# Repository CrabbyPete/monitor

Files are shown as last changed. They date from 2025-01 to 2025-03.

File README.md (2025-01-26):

# crib

## Getting started

To make it easy for you to get started with GitLab, here's a list of recommended next steps.

Already a pro? Just edit this README.md and make it your own. Want to make it easy? [Use the template at the bottom](#editing-this-readme)!

## Add your files

- [ ] [Create](https://docs.gitlab.com/ee/user/project/repository/web_editor.html#create-a-file) or [upload](https://docs.gitlab.com/ee/user/project/repository/web_editor.html#upload-a-file) files
- [ ] [Add files using the command line](https://docs.gitlab.com/ee/gitlab-basics/add-file.html#add-a-file-using-the-command-line) or push an existing Git repository with the following command:

```
cd existing_repo
git remote add origin https://gitlab.com/CrabbyPete/crib.git
git branch -M main
git push -uf origin main
```

## Integrate with your tools

- [ ] [Set up project integrations](https://gitlab.com/CrabbyPete/crib/-/settings/integrations)

## Collaborate with your team

- [ ] [Invite team members and collaborators](https://docs.gitlab.com/ee/user/project/members/)
- [ ] [Create a new merge request](https://docs.gitlab.com/ee/user/project/merge_requests/creating_merge_requests.html)
- [ ] [Automatically close issues from merge requests](https://docs.gitlab.com/ee/user/project/issues/managing_issues.html#closing-issues-automatically)
- [ ] [Enable merge request approvals](https://docs.gitlab.com/ee/user/project/merge_requests/approvals/)
- [ ] [Set auto-merge](https://docs.gitlab.com/ee/user/project/merge_requests/merge_when_pipeline_succeeds.html)

## Test and Deploy

Use the built-in continuous integration in GitLab.

- [ ] [Get started with GitLab CI/CD](https://docs.gitlab.com/ee/ci/quick_start/index.html)
- [ ] [Analyze your code for known vulnerabilities with Static Application Security Testing (SAST)](https://docs.gitlab.com/ee/user/application_security/sast/)
- [ ] [Deploy to Kubernetes, Amazon EC2, or Amazon ECS using Auto Deploy](https://docs.gitlab.com/ee/topics/autodevops/requirements.html)
- [ ] [Use pull-based deployments for improved Kubernetes management](https://docs.gitlab.com/ee/user/clusters/agent/)
- [ ] [Set up protected environments](https://docs.gitlab.com/ee/ci/environments/protected_environments.html)

***

# Editing this README

When you're ready to make this README your own, just edit this file and use the handy template below (or feel free to structure it however you want - this is just a starting point!). Thanks to [makeareadme.com](https://www.makeareadme.com/) for this template.

## Suggestions for a good README

Every project is different, so consider which of these sections apply to yours. The sections used in the template are suggestions for most open source projects. Also keep in mind that while a README can be too long and detailed, too long is better than too short. If you think your README is too long, consider utilizing another form of documentation rather than cutting out information.

## Name
Choose a self-explaining name for your project.

## Description
Let people know what your project can do specifically. Provide context and add a link to any reference visitors might be unfamiliar with. A list of Features or a Background subsection can also be added here. If there are alternatives to your project, this is a good place to list differentiating factors.

## Badges
On some READMEs, you may see small images that convey metadata, such as whether or not all the tests are passing for the project. You can use Shields to add some to your README. Many services also have instructions for adding a badge.

## Visuals
Depending on what you are making, it can be a good idea to include screenshots or even a video (you'll frequently see GIFs rather than actual videos). Tools like ttygif can help, but check out Asciinema for a more sophisticated method.

## Installation
Within a particular ecosystem, there may be a common way of installing things, such as using Yarn, NuGet, or Homebrew. However, consider the possibility that whoever is reading your README is a novice and would like more guidance. Listing specific steps helps remove ambiguity and gets people to using your project as quickly as possible. If it only runs in a specific context like a particular programming language version or operating system or has dependencies that have to be installed manually, also add a Requirements subsection.

## Usage
Use examples liberally, and show the expected output if you can. It's helpful to have inline the smallest example of usage that you can demonstrate, while providing links to more sophisticated examples if they are too long to reasonably include in the README.

## Support
Tell people where they can go to for help. It can be any combination of an issue tracker, a chat room, an email address, etc.

## Roadmap
If you have ideas for releases in the future, it is a good idea to list them in the README.

## Contributing
State if you are open to contributions and what your requirements are for accepting them.

For people who want to make changes to your project, it's helpful to have some documentation on how to get started. Perhaps there is a script that they should run or some environment variables that they need to set. Make these steps explicit. These instructions could also be useful to your future self.

You can also document commands to lint the code or run tests. These steps help to ensure high code quality and reduce the likelihood that the changes inadvertently break something. Having instructions for running tests is especially helpful if it requires external setup, such as starting a Selenium server for testing in a browser.

## Authors and acknowledgment
Show your appreciation to those who have contributed to the project.

## License
For open source projects, say how it is licensed.

## Project status
If you have run out of energy or time for your project, put a note at the top of the README saying that development has slowed down or stopped completely. Someone may choose to fork your project or volunteer to step in as a maintainer or owner, allowing your project to keep going. You can also make an explicit request for maintainers.

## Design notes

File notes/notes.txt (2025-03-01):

How to build:

1. Install Bullseye 64bit Lite OS
2. sudo apt update, sudo apt upgrade
3. copy config.txt
4. copy /etc/asound.conf

Audio:
    with no asound.conf: # volume is very low lasts 2 seconds
    arecord -f S32_LE -D hw:0,0 -c 2 -r 48000 -d 2 test.wav

    Stream audio to speakers
    gst-launch-1.0 alsasrc device=hw:0 ! autoaudiosink
    gst-launch-1.0 alsasrc device=hw:0 ! volume volume=3.0 ! autoaudiosink

    Audio only to VLC
    gst-launch-1.0 alsasrc device=hw:1,0 ! mulawenc ! rtppcmupay ! udpsink host=224.1.1.1 auto-multicast=true port=5000
    Now VLC works going to rtp://224.1.1.1:5000 and has the correct codec that I wanted.

Install gstream python

    sudo apt install libcairo2-dev pkg-config python3-dev
    pip install pycairo
    pip install PyGObject

To add awswebrtcsink
    https://gitlab.freedesktop.org/gstreamer/gst-plugins-rs/-/blob/main/net/webrtc/README.md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

Links:
https://learn.adafruit.com/adafruit-max98357-i2s-class-d-mono-amp/raspberry-pi-wiring
https://www.raspberrypi.com/documentation/computers/camera_software.html
https://sourceforge.net/p/raspberry-gpio-python/wiki
https://www.linkedin.com/pulse/streaming-camera-video-aws-kinesis-streams-using-python-kashif-ayub-map9f/
https://docs.arducam.com/Raspberry-Pi-Camera/Low-Light/quick-start/#native-camera
https://github.com/dave-malone/aws-kvs-webrtc-demo-for-raspberry-pi

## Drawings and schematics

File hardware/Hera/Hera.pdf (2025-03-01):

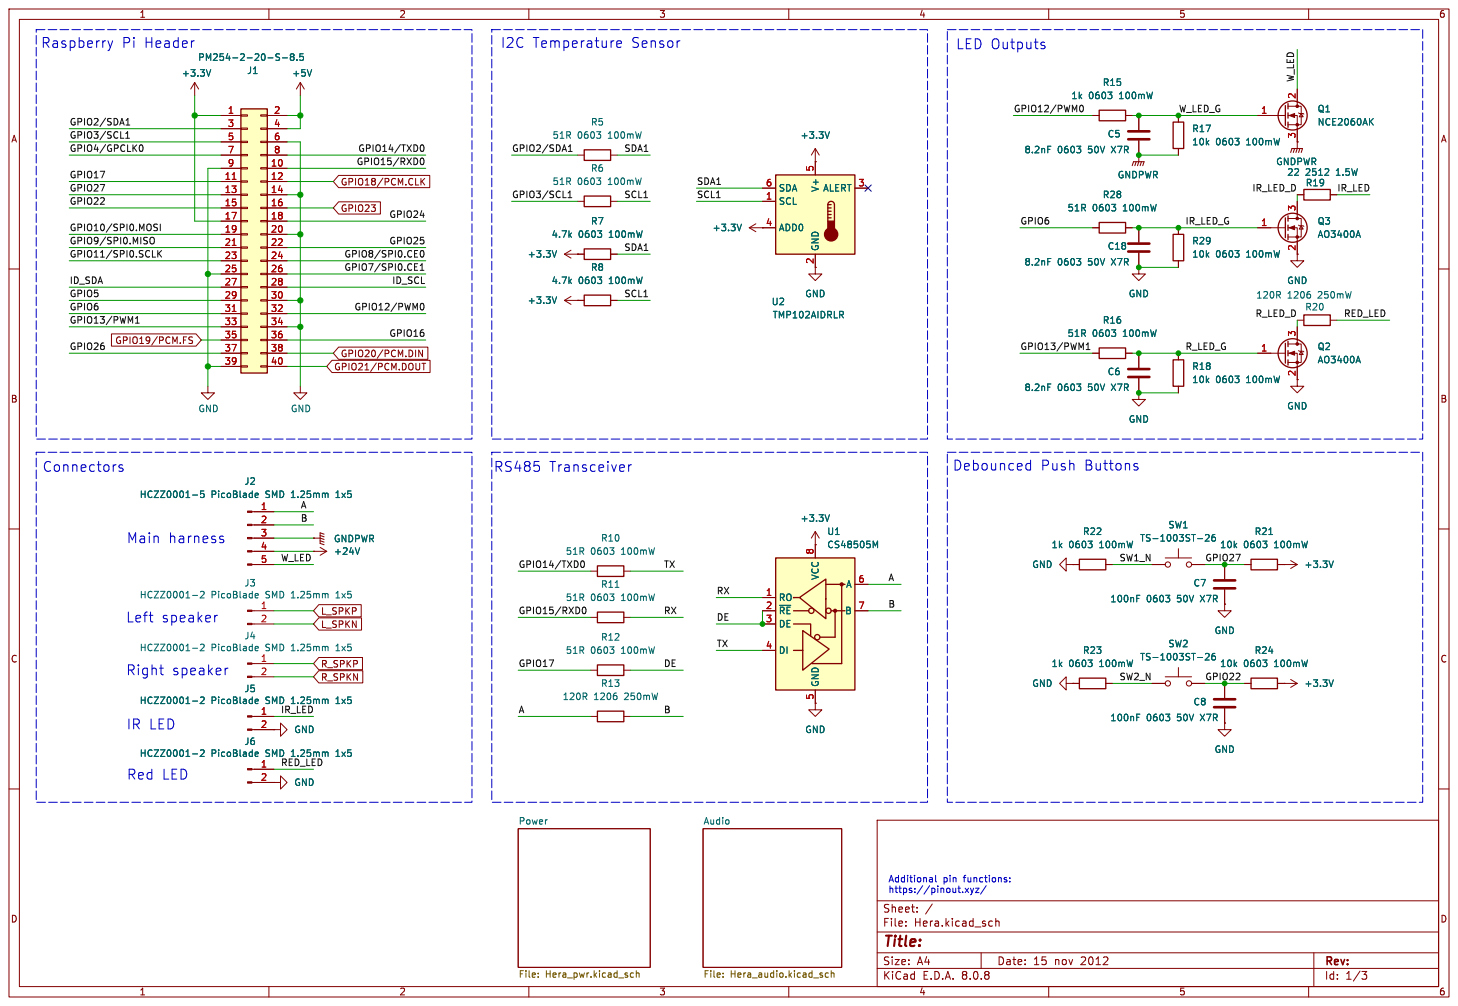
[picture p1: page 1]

GND GND GPIO20/PCM.DIN GPIO21/PCM.DOUT GPIO18/PCM.CLK

Id: 1/3 Title: File: Hera.kicad_sch Sheet: / Audio File: Hera_audio.kicad_sch Power File: Hera_pwr.kicad_sch

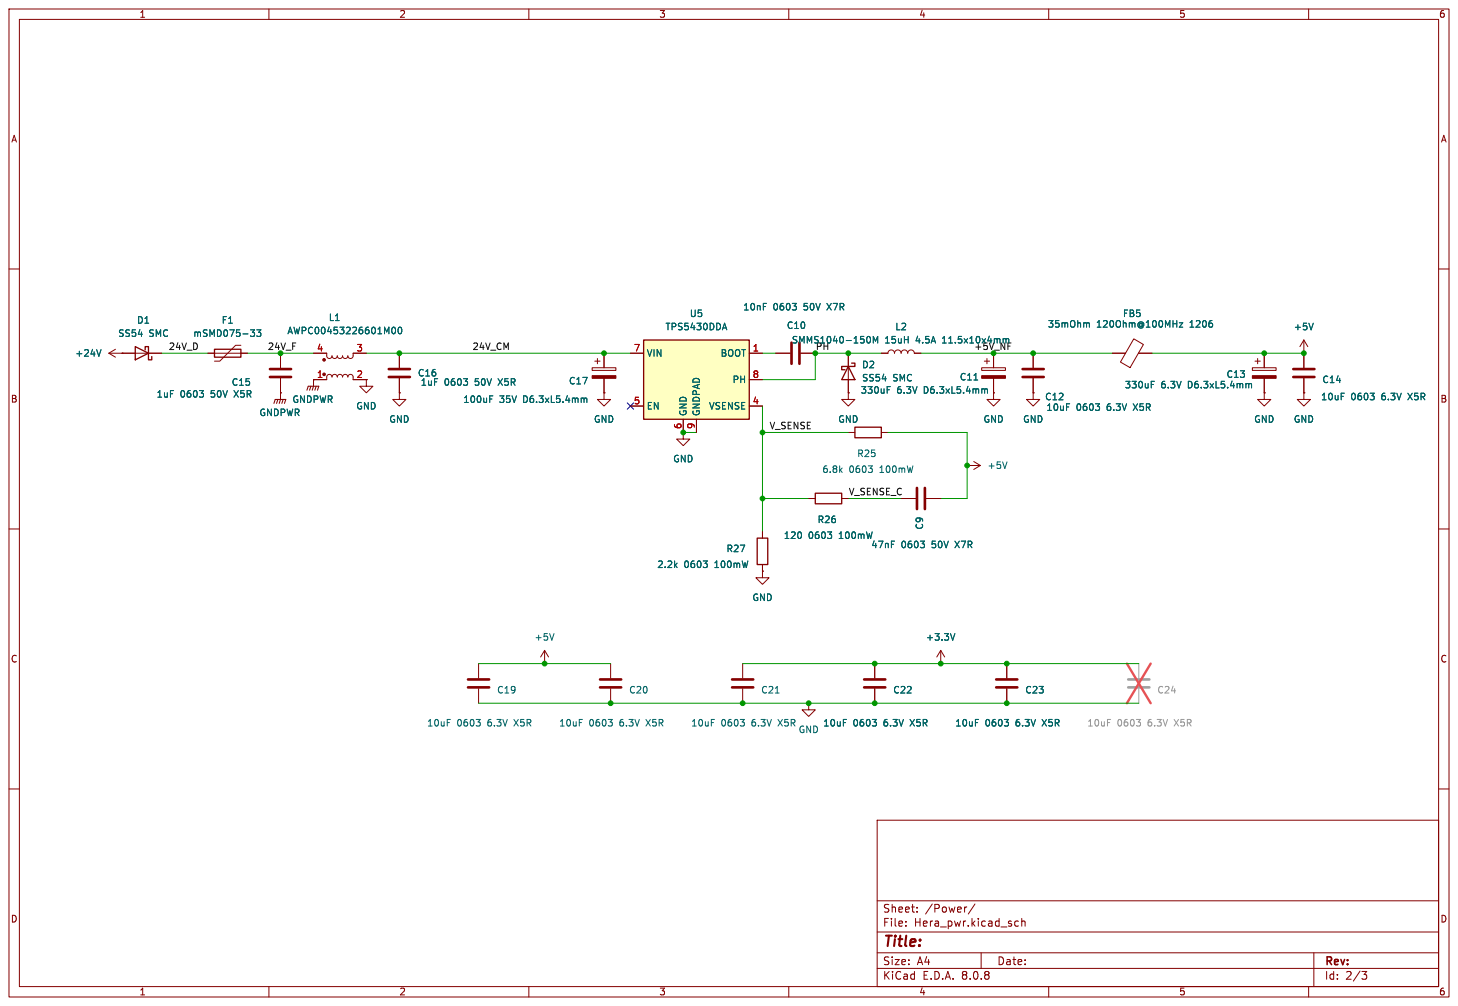
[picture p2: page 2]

Id: 2/3 Title: File: Hera_pwr.kicad_sch Sheet: /Power/ C9

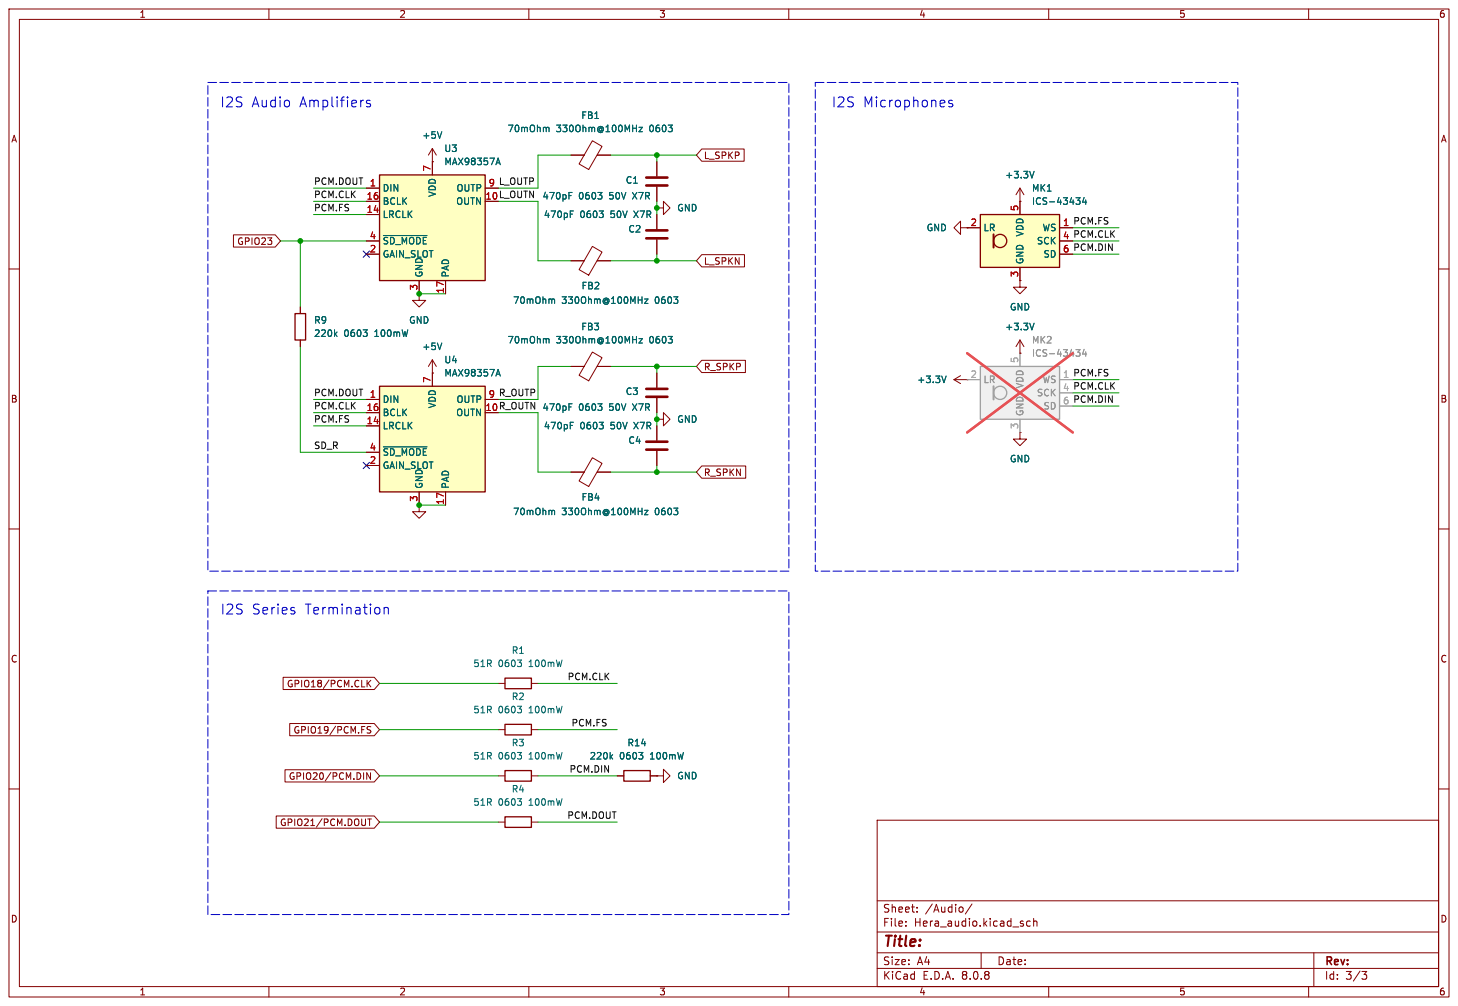
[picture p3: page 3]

PCM.DOUT PCM.FS

R_SPKP GPIO19/PCM.FS GPIO18/PCM.CLK GPIO20/PCM.DIN

Id: 3/3 Title: File: Hera_audio.kicad_sch Sheet: /Audio/ R2

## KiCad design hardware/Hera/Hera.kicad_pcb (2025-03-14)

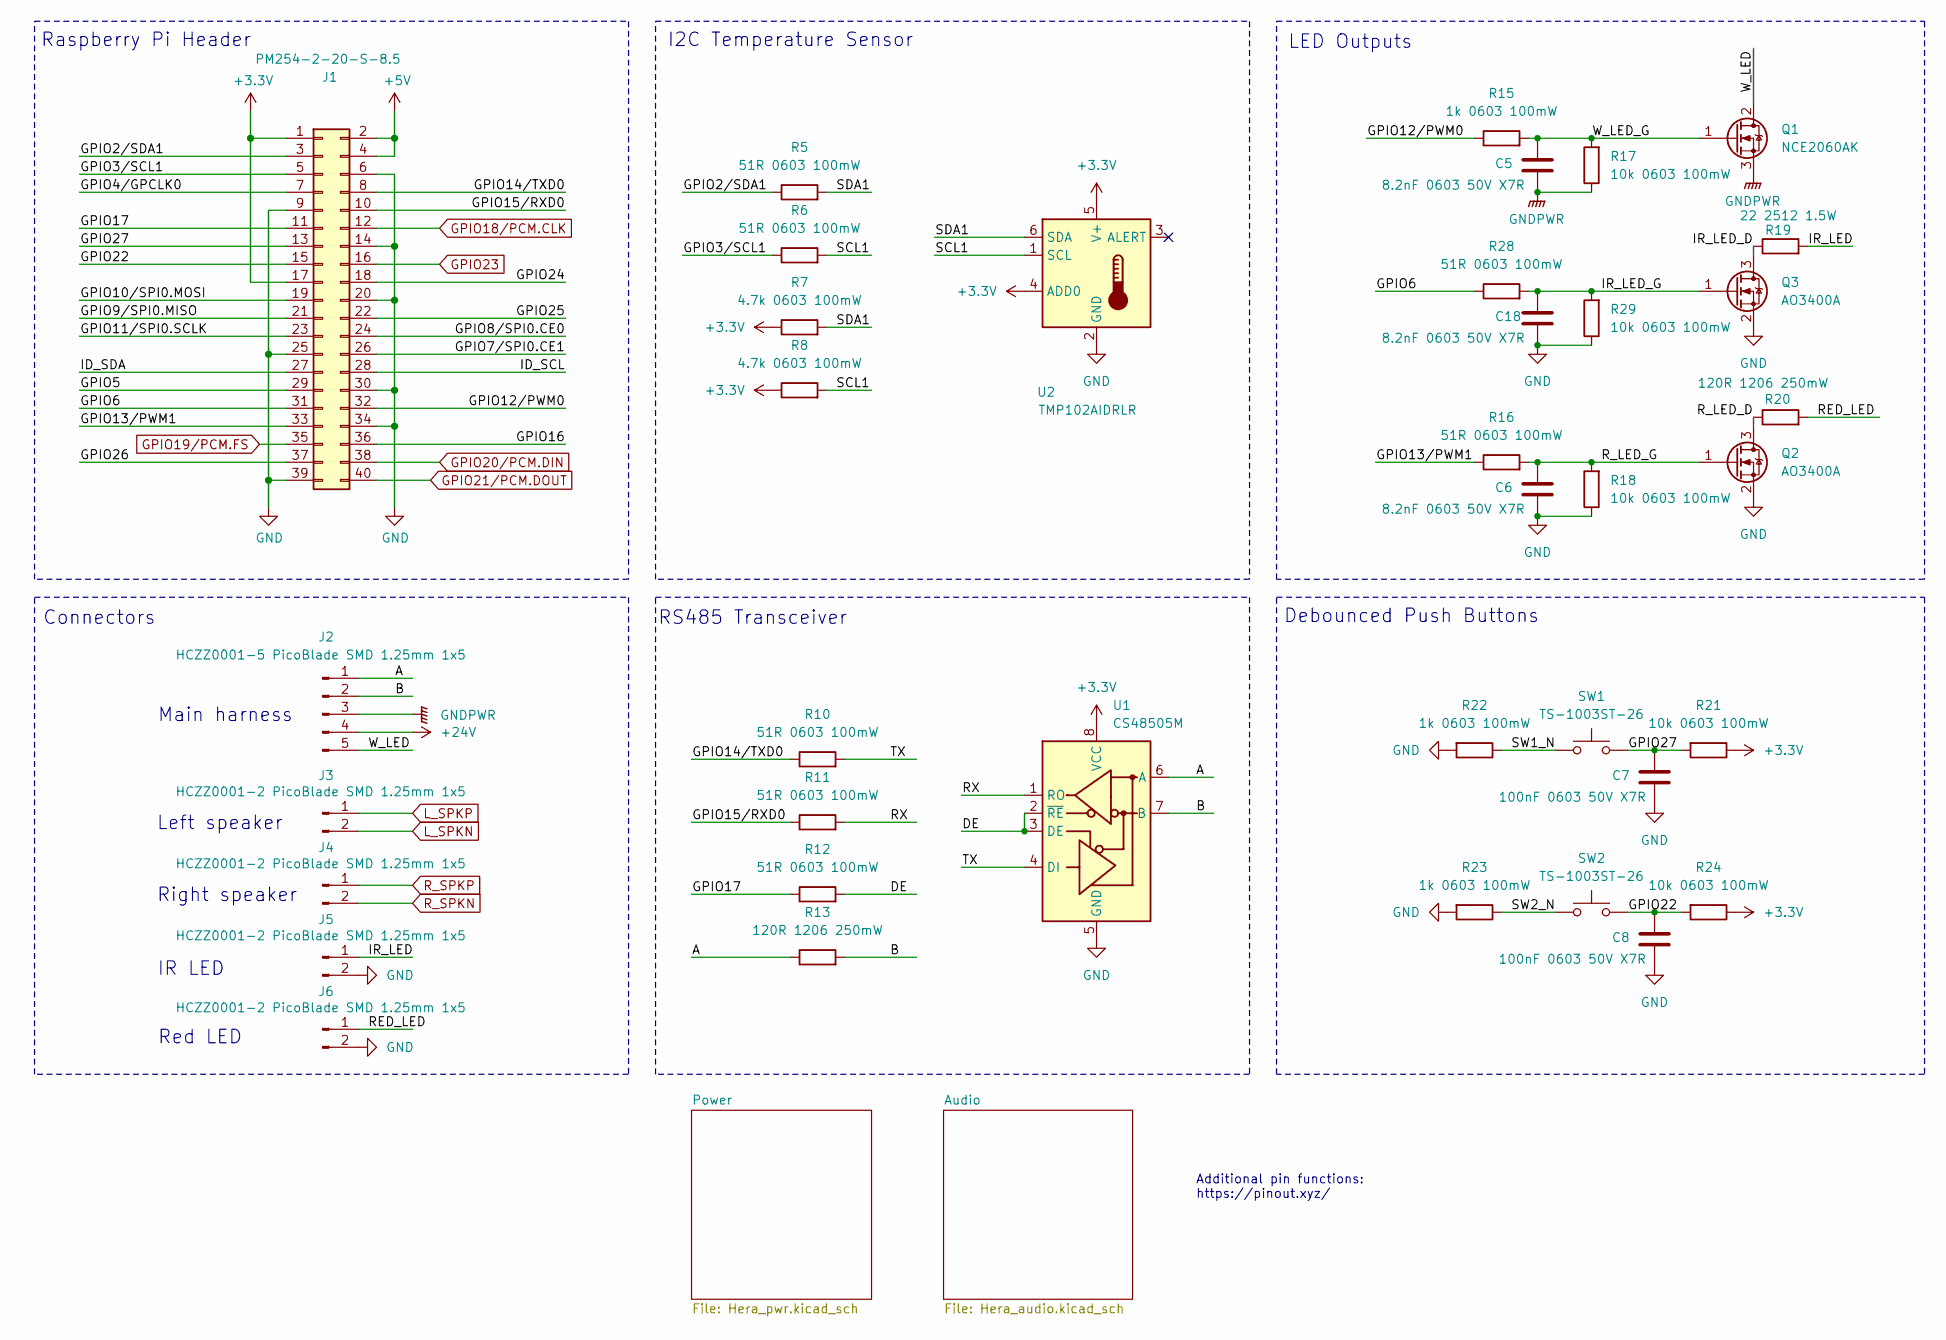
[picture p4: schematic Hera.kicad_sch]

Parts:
C5, C6, C18: 8.2nF 0603 50V X7R; C_0603_1608Metric
C7, C8: 100nF 0603 50V X7R; C_0603_1608Metric
J1: PM254-2-20-S-8.5; PinSocket_2x20_P2.54mm_Vertical_SMD
J2: HCZZ0001-5 PicoBlade SMD 1.25mm 1x5; Molex_PicoBlade_53261-0571_1x05-1MP_P1.25mm_Horizontal
J3, J4, J5, J6: HCZZ0001-2 PicoBlade SMD 1.25mm 1x5; Molex_PicoBlade_53261-0271_1x02-1MP_P1.25mm_Horizontal
Q1: NCE2060AK; TO-252-2
Q2, Q3: AO3400A; SOT-23
R5, R6, R10, R11, R12, R16, R28: 51R 0603 100mW; R_0603_1608Metric
R7, R8: 4.7k 0603 100mW; R_0603_1608Metric
R13, R20: 120R 1206 250mW; R_1206_3216Metric
R15, R22, R23: 1k 0603 100mW; R_0603_1608Metric
R17, R18, R21, R24, R29: 10k 0603 100mW; R_0603_1608Metric
R19: 22 2512 1.5W; R_2512_6332Metric
SW1, SW2: TS-1003ST-26; SW_Push_1P1T_NO_CK_PTS125Sx43PSMTR
U1: CS48505M; MSOP-8_3x3mm_P0.65mm
U2: TMP102AIDRLR; SOT-563

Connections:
+3.3V: J1.1, J1.17, R7.1, R8.1, R21.1, R24.1, U1.8 (VCC), U2.4 (ADD0), U2.5 (V+); also elsewhere on the board
+5V: J1.2, J1.4; also elsewhere on the board
+24V: J2.4; also elsewhere on the board
/A: J2.1, R13.1, U1.6 (A)
/B: J2.2, R13.2, U1.7 (B)
/DE: R12.2, U1.2 (~RE), U1.3 (DE)
/GPIO2/SDA1: J1.3, R5.1
/GPIO3/SCL1: J1.5, R6.1
/GPIO4/GPCLK0: J1.7
/GPIO5: J1.29
/GPIO6: J1.31, R28.1
/GPIO7/SPI0.CE1: J1.26
/GPIO8/SPI0.CE0: J1.24
/GPIO9/SPI0.MISO: J1.21
/GPIO10/SPI0.MOSI: J1.19
/GPIO11/SPI0.SCLK: J1.23
/GPIO12/PWM0: J1.32, R15.1
/GPIO13/PWM1: J1.33, R16.1
/GPIO14/TXD0: J1.8, R10.1
/GPIO15/RXD0: J1.10, R11.1
/GPIO16: J1.36
/GPIO17: J1.11, R12.1
/GPIO22: C8.1, J1.15, R24.2, SW2.2
/GPIO24: J1.18
/GPIO25: J1.22
/GPIO26: J1.37
/GPIO27: C7.1, J1.13, R21.2, SW1.2
/ID_SCL: J1.28
/ID_SDA: J1.27
/IR_LED: J5.1, R19.2
/IR_LED_D: Q3.3 (D), R19.1
/IR_LED_G: C18.1, Q3.1 (G), R28.2, R29.2
/RED_LED: J6.1, R20.2
/RX: R11.2, U1.1 (RO)
/R_LED_D: Q2.3 (D), R20.1
/R_LED_G: C6.1, Q2.1 (G), R16.2, R18.2
/SCL1: R6.2, R8.2, U2.1 (SCL)
/SDA1: R5.2, R7.2, U2.6 (SDA)
/SW1_N: R22.1, SW1.1
/SW2_N: R23.1, SW2.1
/TX: R10.2, U1.4 (DI)
/W_LED: J2.5, Q1.2 (D)
/W_LED_G: C5.1, Q1.1 (G), R15.2, R17.2
GND: C6.2, C7.2, C8.2, C18.2, J1.6, J1.9, J1.14, J1.20, J1.25, J1.30, J1.34, J1.39, J5.2, J6.2, Q2.2 (S), Q3.2 (S), R18.1, R22.2, R23.2, R29.1, U1.5 (GND), U2.2 (GND); also elsewhere on the board
GNDPWR: C5.2, J2.3, Q1.3 (S), R17.1; also elsewhere on the board
GPIO18/PCM.CLK: J1.12; also elsewhere on the board
GPIO19/PCM.FS: J1.35; also elsewhere on the board
GPIO20/PCM.DIN: J1.38; also elsewhere on the board
GPIO21/PCM.DOUT: J1.40; also elsewhere on the board
GPIO23: J1.16; also elsewhere on the board
L_SPKN: J3.2; also elsewhere on the board
L_SPKP: J3.1; also elsewhere on the board
R_SPKN: J4.2; also elsewhere on the board
R_SPKP: J4.1; also elsewhere on the board

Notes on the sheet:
Red LED
RS485 Transceiver
Main harness
IR LED
Right speaker
Left speaker
LED Outputs
Raspberry Pi Header
Connectors
I2C Temperature Sensor
Debounced Push Buttons
Additional pin functions: https://pinout.xyz/

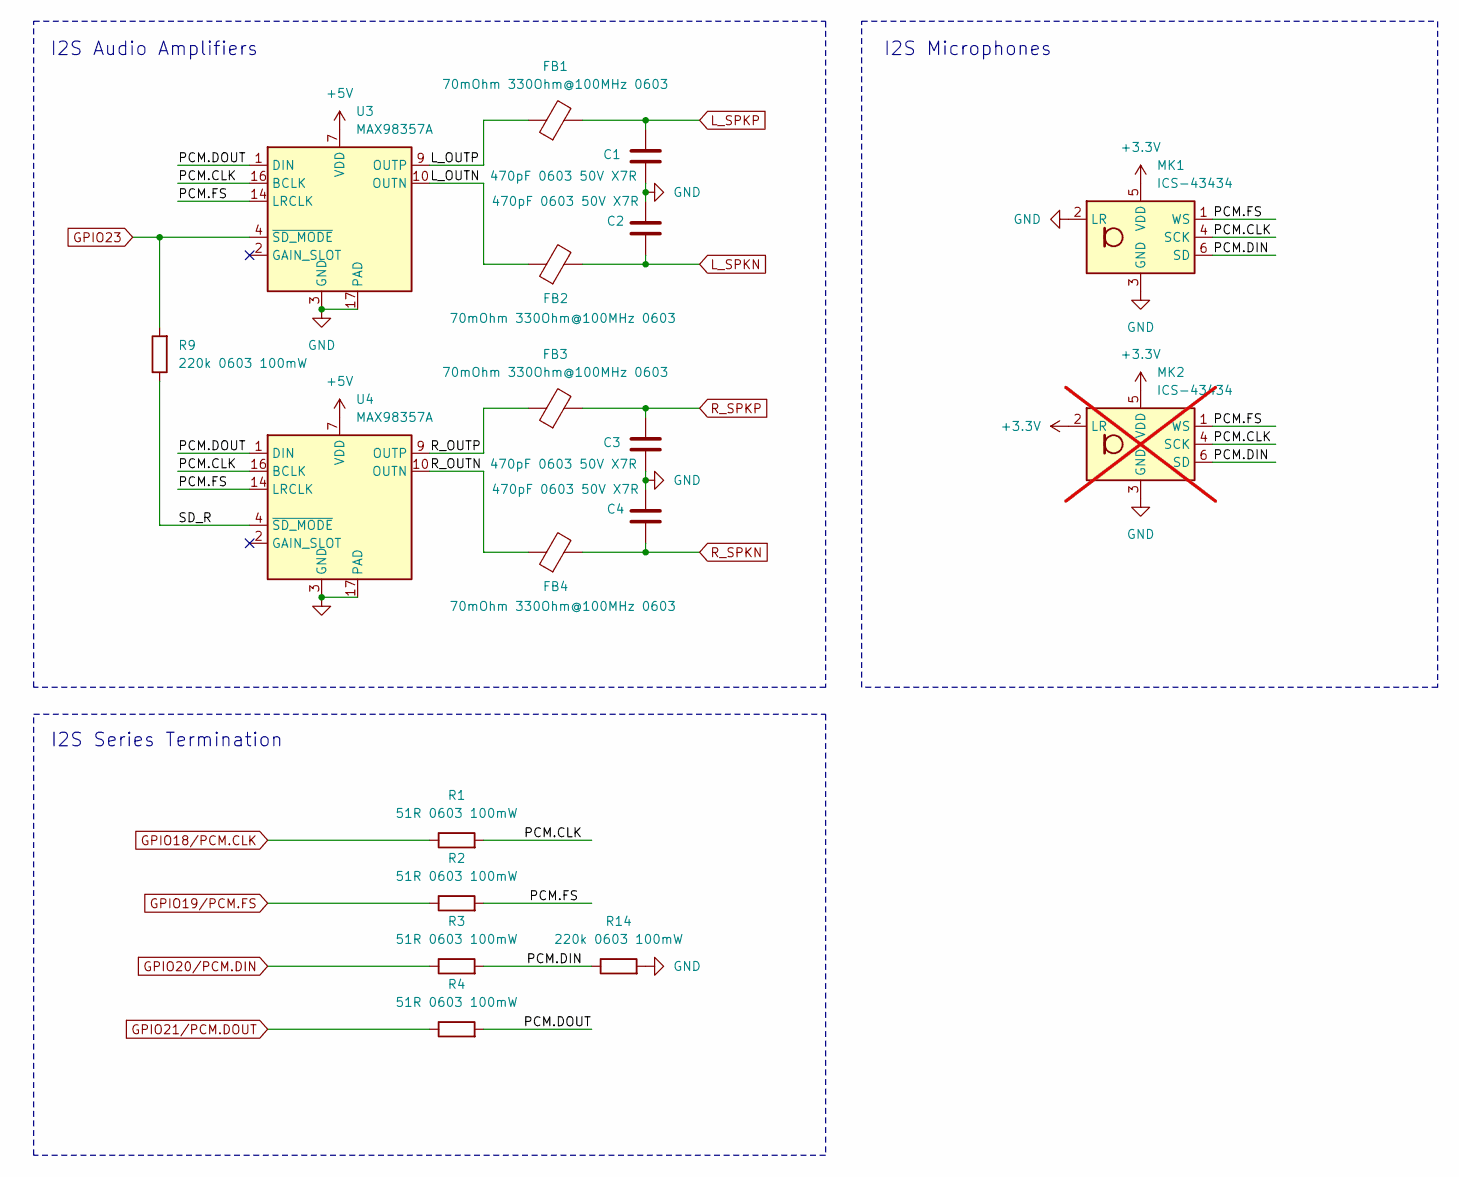
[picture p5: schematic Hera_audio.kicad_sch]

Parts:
C1, C2, C3, C4: 470pF 0603 50V X7R; C_0603_1608Metric
FB1, FB2, FB3, FB4: 70mOhm 330Ohm@100MHz 0603; L_0603_1608Metric
MK1: ICS-43434; InvenSense_ICS-43434-6_3.5x2.65mm
MK2: ICS-43434; InvenSense_ICS-43434-6_3.5x2.65mm; not fitted
R1, R2, R3, R4: 51R 0603 100mW; R_0603_1608Metric
R9, R14: 220k 0603 100mW; R_0603_1608Metric
U3, U4: MAX98357A; TQFN-16-1EP_3x3mm_P0.5mm_EP1.23x1.23mm

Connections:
+3.3V: MK1.5 (VDD), MK2.2 (LR), MK2.5 (VDD); also elsewhere on the board
+5V: U3.7 (VDD), U3.8 (VDD), U4.7 (VDD), U4.8 (VDD); also elsewhere on the board
/Audio/L_OUTN: FB2.1, U3.10 (OUTN)
/Audio/L_OUTP: FB1.1, U3.9 (OUTP)
/Audio/PCM.CLK: MK1.4 (SCK), MK2.4 (SCK), R1.2, U3.16 (BCLK), U4.16 (BCLK)
/Audio/PCM.DIN: MK1.6 (SD), MK2.6 (SD), R3.2, R14.1
/Audio/PCM.DOUT: R4.2, U3.1 (DIN), U4.1 (DIN)
/Audio/PCM.FS: MK1.1 (WS), MK2.1 (WS), R2.2, U3.14 (LRCLK), U4.14 (LRCLK)
/Audio/R_OUTN: FB4.1, U4.10 (OUTN)
/Audio/R_OUTP: FB3.1, U4.9 (OUTP)
/Audio/SD_R: R9.1, U4.4 (~SD_MODE)
GND: C1.2, C2.1, C3.2, C4.1, MK1.2 (LR), MK1.3 (GND), MK2.3 (GND), R14.2, U3.3 (GND), U3.11 (GND), U3.15 (GND), U3.17 (PAD), U4.3 (GND), U4.11 (GND), U4.15 (GND), U4.17 (PAD); also elsewhere on the board
GPIO18/PCM.CLK: R1.1; also elsewhere on the board
GPIO19/PCM.FS: R2.1; also elsewhere on the board
GPIO20/PCM.DIN: R3.1; also elsewhere on the board
GPIO21/PCM.DOUT: R4.1; also elsewhere on the board
GPIO23: R9.2, U3.4 (~SD_MODE); also elsewhere on the board
L_SPKN: C2.2, FB2.2; also elsewhere on the board
L_SPKP: C1.1, FB1.2; also elsewhere on the board
R_SPKN: C4.2, FB4.2; also elsewhere on the board
R_SPKP: C3.1, FB3.2; also elsewhere on the board

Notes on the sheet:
I2S Audio Amplifiers
I2S Microphones
I2S Series Termination

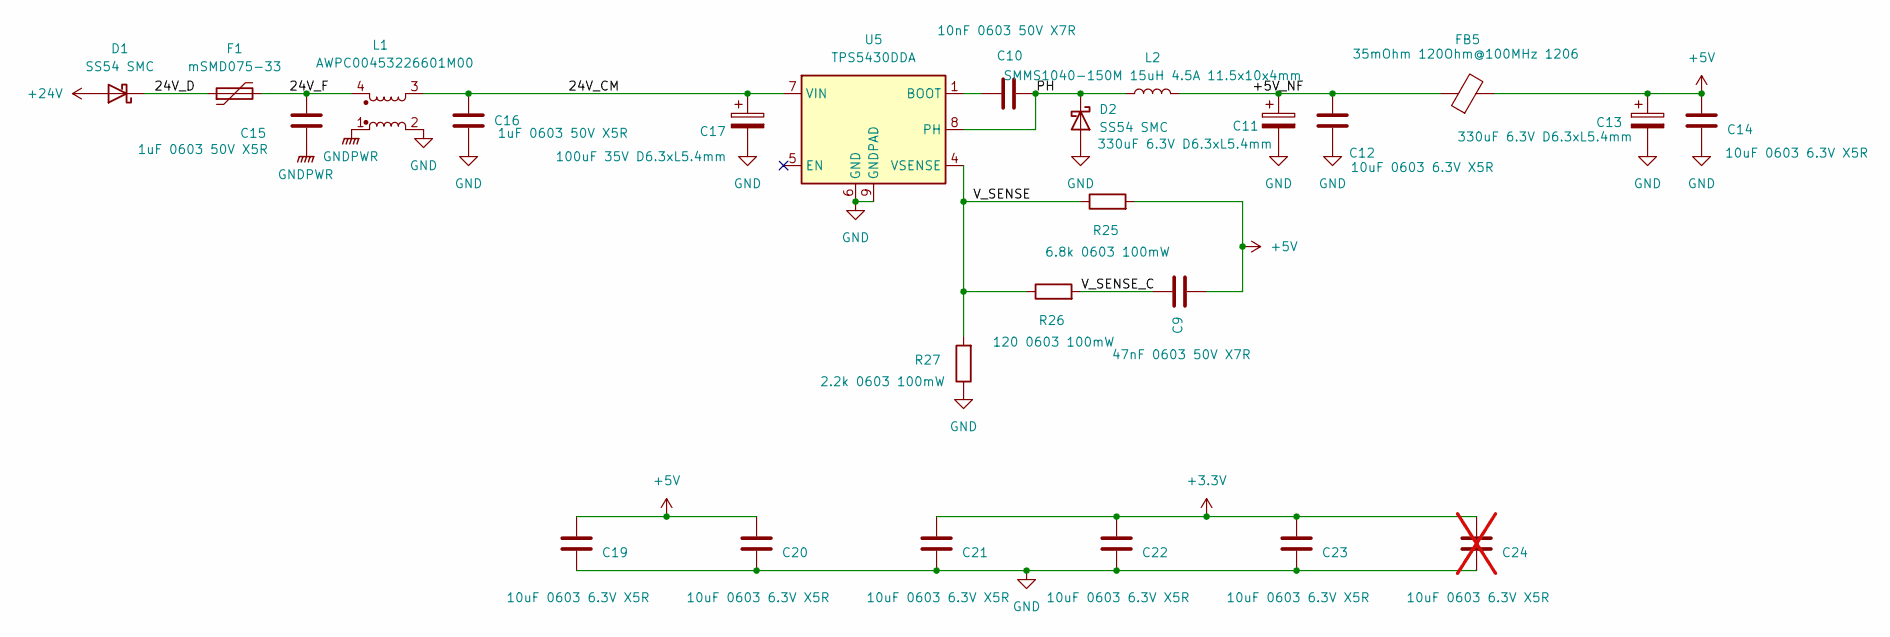
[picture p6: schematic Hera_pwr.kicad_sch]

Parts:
C9: 47nF 0603 50V X7R; C_0603_1608Metric
C10: 10nF 0603 50V X7R; C_0603_1608Metric
C11, C13: 330uF 6.3V D6.3xL5.4mm; CP_Elec_6.3x5.4
C12, C14, C19, C20, C21, C22, C23: 10uF 0603 6.3V X5R; C_0603_1608Metric
C15, C16: 1uF 0603 50V X5R; C_0603_1608Metric
C17: 100uF 35V D6.3xL5.4mm; CP_Elec_6.3x5.4
C24: 10uF 0603 6.3V X5R; C_0603_1608Metric; not fitted
D1, D2: SS54 SMC; D_SMC
F1: mSMD075-33; Fuse_1812_4532Metric
FB5: 35mOhm 120Ohm@100MHz 1206; L_1206_3216Metric
L1: AWPC00453226601M00; L_CommonModeChoke_4.5x3.2
L2: SMMS1040-150M 15uH 4.5A 11.5x10x4mm; L_APV_APH1040
R25: 6.8k 0603 100mW; R_0603_1608Metric
R26: 120 0603 100mW; R_0603_1608Metric
R27: 2.2k 0603 100mW; R_0603_1608Metric
U5: TPS5430DDA; TI_SO-PowerPAD-8_ThermalVias

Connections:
+3.3V: C21.2, C22.2, C23.2, C24.2; also elsewhere on the board
+5V: C9.2, C13.1, C14.2, C19.2, C20.2, FB5.2, R25.2; also elsewhere on the board
+24V: D1.2 (A); also elsewhere on the board
/Power/24V_CM: C16.2, C17.1, L1.3, U5.7 (VIN)
/Power/24V_D: D1.1 (K), F1.1
/Power/24V_F: C15.2, F1.2, L1.4
/Power/+5V_NF: C11.1, C12.2, FB5.1, L2.2
/Power/PH: C10.1, D2.1 (K), L2.1, U5.8 (PH)
/Power/V_SENSE: R25.1, R26.1, R27.2, U5.4 (VSENSE)
/Power/V_SENSE_C: C9.1, R26.2
GND: C11.2, C12.1, C13.2, C14.1, C16.1, C17.2, C19.1, C20.1, C21.1, C22.1, C23.1, C24.1, D2.2 (A), L1.2, R27.1, U5.6 (GND), U5.9 (GNDPAD); also elsewhere on the board
GNDPWR: C15.1, L1.1; also elsewhere on the board
unnamed: C10.2, U5.1 (BOOT)

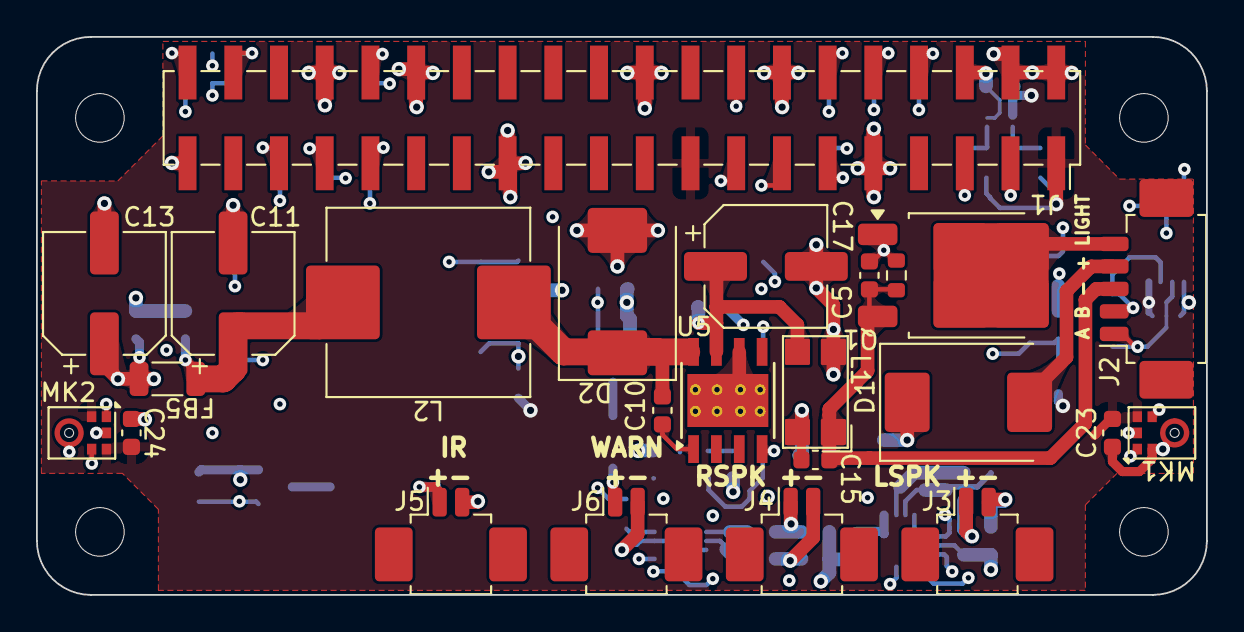
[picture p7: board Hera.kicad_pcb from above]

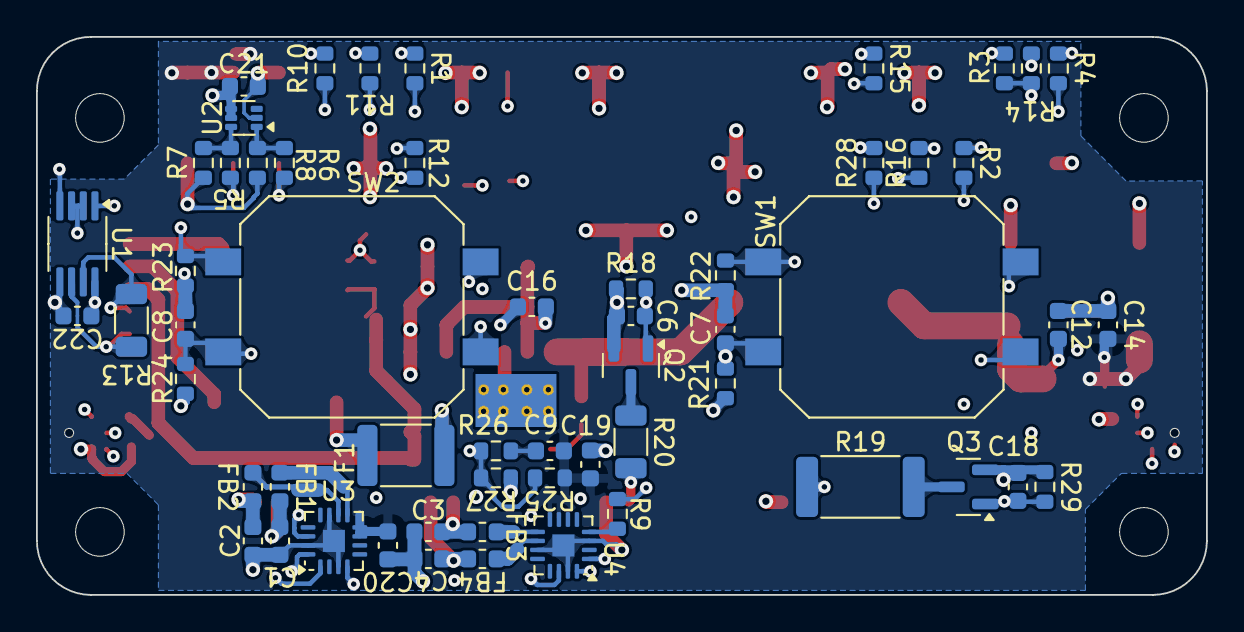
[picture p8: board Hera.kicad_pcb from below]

Board: 6 copper layers, 65.0 x 31.0 mm, 85 parts (57 on the bottom side), 58 nets.

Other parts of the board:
MH1, MH2, MH3, MH4: MountingHole_2.7mm_M2.5

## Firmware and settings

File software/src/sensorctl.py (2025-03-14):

#!/usr/bin/env python3
import os
import time
import smbus2
import psutil
import subprocess
import RPi.GPIO as GPIO

# Local imports
from log        import log
from status     import state
from bare485    import Modbus

MIN_DUTY = 0
MAX_DUTY = 100
MOTOR_CHANNEL = '/dev/ttyS0' # If you uses the USB use this /dev/ttyUSB0'

BUTTON_1_CHANNEL = 27
BUTTON_2_CHANNEL = 22

LED_CHANNEL = 12        # PWM LED channel
LED_FREQUENCY = 10000
IR_LED_CHANNEL = 6
RED_LED_CHANNEL = 13
SPEAKERS = 23

HOME = os.path.dirname(os.path.realpath(__file__))

GPIO.setwarnings(False)
GPIO.setmode(GPIO.BCM)

GPIO.setup(LED_CHANNEL, GPIO.OUT )
GPIO.setup(IR_LED_CHANNEL, GPIO.OUT )
GPIO.setup(RED_LED_CHANNEL, GPIO.OUT)
GPIO.setup(SPEAKERS, GPIO.OUT)


def get_serial():
    """
    Get the system serial number of this Pi
    :return: str: serial number
    """
    with os.popen("cat /proc/cpuinfo | grep Serial | cut -d ' ' -f 2 | md5sum | cut -d ' ' -f 1") as fp:
        serial = fp.read().splitlines()[0]
    return serial


def red_led(command, *values):
    """
    Turn on and off red light
    :param command: str 'on'|'off
    :return:
    """
    log.info(f"red_led {command},{values}")
    value = 1 if command == 'on' else 0
    GPIO.output(RED_LED_CHANNEL, value)
    state.red_led = value
    return value


def ir_led(command, *values):
    """
    Turn on and off IR LED
    :param command: str: 'on'|'off
    :return:
    """
    value = 1 if command == 'on' else 0
    GPIO.output(IR_LED_CHANNEL, value)
    state.ir_led = value
    return value


pwm = GPIO.PWM(LED_CHANNEL, LED_FREQUENCY)
pwm.start(0)


def lights(command, *values):
    """
    Turn on and off the leds
    :param command: str: on, off, boost, or integer value
    :param values: option value for a given command
    :return:
    """
    log.info(f"lights {command} {values}")

    # Current state has to be a percentage of the maximum duty cycle 255.
    if values:
        if isinstance(values[0], str):
            try:
                value = int(values[0])
            except TypeError:
                log.error(f"Type error in lights for {values}")
        else:
            try:
                value = int(values[0])
            except TypeError:
                value = 0

    if command == 'on':
        duty_cycle = 50

    elif command == 'boost':
        duty_cycle = MAX_DUTY

    elif command == 'off':
        duty_cycle = 0

    elif command == 'adjust':
        # Adjust the current value by percent of current value # Note the app is sending this after an 'off'
        current, _ = state.lights
        current = int(current) + values[0]
        current = min(max(current,0),100)
        duty_cycle = int( MAX_DUTY * ( current / 100 ))

    elif command == 'set':
        value = min(max(values[0],0),100)
        duty_cycle = int( MAX_DUTY * ( value / 100 ))

    elif command == 'blink':
        # Blink the lights value times
        current_state = int(state.lights[0])

        for _ in range(value):
            pwm.ChangeDutyCycle(100)
            time.sleep(1)

            pwm.ChangeDutyCycle(0)
            time.sleep(1)

        duty_cycle = current_state

    # print(f"duty_cycle:{duty_cycle}")
    pwm.ChangeDutyCycle(duty_cycle)
    state.lights = duty_cycle

    return duty_cycle


def speakers(command, *values):
    """
    Ploy or stop sound from the speakers
    :param command: 'play' or 'stop
    :param values: str: name of file to play
    :return:
    """
    enable = GPIO.input(SPEAKERS)
    GPIO.output(SPEAKERS, 1)
    log.info(f"Speakers:{command}:{values}")
    if not values:
        tunes = ['lullaby.wav']
    else:
        if values[0]:
            tunes = list(values[0])
        else:
            tunes = ['lullaby.wav']

    if command == 'play':
        ok = False
        for tune in tunes:
            value = os.path.join(HOME, tune)
            command = f"aplay {value}"
            ok = subprocess.Popen(command.split(), stderr=subprocess.PIPE, stdout=subprocess.PIPE)
            if ok.returncode:
                log.error(f"Error:{ok.returncode} running {command}")
            else:
                state.speakers = (['on', ok.pid])
        return ok

    elif command == 'stop':
        pass



def microphone(command, *values):
    """
    Turn on and off the microphone
    :param command:
    :return:
    """
    # Send audio output to process or socket
    if command == 'on':
        command = "arecord -D plughw:0 -c1 -r 48000 -f S32_LE -t wav file.wav"
        ok = subprocess.run(command.split(), stderr=subprocess.PIPE, stdout=subprocess.PIPE)
    else:
        pass


def record(command, *options):
    """
    Manage recording
    :param command: str: on or off
    :param options: n
    :return:
    """
    pass


def motor(command, *values):
    """
    Get the current water level
    :return:
    """
    try:
        sm = Modbus(MOTOR_CHANNEL)
    except Exception as e:
        log.error(f"Error:{e} trying to connect to motor")
        return False

    speed = sm.get_speed()
    on_off = state.motor[0]

    if command == 'on':
        ok = sm.start()
        on_off = 'on'

    elif command == 'off':
        ok = sm.stop()
        on_off = 'off'

    elif command == 'reverse':
        sm.reverse()

    elif command == 'speed':
        sm.speed(values[0])

    state.motor([on_off, speed])
    return on_off, speed


def i2c_scan(bus_number=1):
    """Scans the I2C bus for devices."""
    bus_addresses = []
    with smbus2.SMBus(bus_number) as bus:
        for address in range(0x08, 0x79):
            try:
                bus.read_byte(address)
                bus_addresses.append(address)
            except Exception:
                pass
    return bus_addresses


def temperature(bus=1, address=0x49):
    """
    Read the tmp102 temperature and humidity sensor
    :param bus: I2C bus
    :param address: I2C address of the device
    :return set temperature humidity
    """
    def twos_comp(val, bits):
        if (val & (1 << (bits - 1))) != 0:
            val = val - (1 << bits)
        return val

    with smbus2.SMBus(1) as bus:

        # Read the configuration block
        data = bus.read_i2c_block_data(address, 0x01, 2)

        # Set to 4 Hz sampling (CR1, CR0 = 0b10)
        data[1] = data[1] & 0b00111111
        data[1] = data[1] | (0b10 << 6)

        # Write 4 Hz sampling back to CONFIG
        bus.write_i2c_block_data(address, 0x01, data)

        val = bus.read_i2c_block_data(address, 0x00, 2)
        temp_c = (val[0] << 4) | (val[1] >> 4)
        temp_c = twos_comp(temp_c, 12)

    # Convert registers value to temperature (C)
    temp_c = temp_c * 0.0625
    state.temperature = temp_c
    return temp_c


# Keep track of microseconds elapsed since fall and rise
tick_down=[0,0]

def button_callback(channel):
    global tick_down

    up = GPIO.input(channel)
    print(channel, up)

    # Keep track of the time for each button
    tick:int =  0 if channel == BUTTON_1_CHANNEL else 1

    # If the button is down, record starting time until it comes up
    if not up:
        print('d')
        tick_down[tick] = time.time()
    else:
        print('u')
        hold = time.time() - tick_down[tick]
        if channel == BUTTON_1_CHANNEL:
            if hold > 1.:
                if not int(state.lights[0]):
                    lights('on')
                else:
                    lights('off')
        else:
            print("play")
            pass



def buttons():
    """
    Set up the buttons. Make sure the process that calls this waits forever
    :return: None
    """
    GPIO.setup(BUTTON_1_CHANNEL, GPIO.IN, pull_up_down=GPIO.PUD_UP)
    GPIO.setup(BUTTON_2_CHANNEL, GPIO.IN, pull_up_down=GPIO.PUD_UP)

    try:
        GPIO.add_event_detect(BUTTON_1_CHANNEL, GPIO.BOTH, callback=button_callback, bouncetime=500)
    except Exception as e:
        log.error(f"Error:{e} on {BUTTON_1_CHANNEL}")
    try:
        GPIO.add_event_detect(BUTTON_2_CHANNEL, GPIO.BOTH, callback=button_callback, bouncetime=500)
    except Exception as e:
        log.error(f"Error:{e} on {BUTTON_2_CHANNEL}")



def cpu():
    """
    Get the cpu temperature
    """
    try:
        with open('/sys/class/thermal/thermal_zone0/temp') as f:
            cpu_temp = f.read()
    except Exception as e:
        cpu_temp = 'error'
        log.error("Error:{} reading cpu temperature".format(str(e)))
    else:
        cpu_temp = float(cpu_temp) / 1000
    state.cpu = cpu_temp

    return cpu_temp


def wifi_signal():
    """
    Get the current wifi signal and essig
    """
    command = "iwconfig wlan0"
    ok = subprocess.run(command.split(), stderr=subprocess.PIPE, stdout=subprocess.PIPE)
    if ok.returncode:
        log.error("Error:{}  reading iwconfig".format(ok.stderr))
        return {}
    """
    wlan0     IEEE 802.11  ESSID:"NETGEAR59"
          Mode:Managed  Frequency:2.442 GHz  Access Point: 9C:D3:6D:A5:9F:E4
          Bit Rate=72.2 Mb/s   Tx-Power=31 dBm
          Retry short limit:7   RTS thr:off   Fragment thr:off
          Power Management:on
          Link Quality=61/70  Signal level=-49 dBm
          Rx invalid nwid:0  Rx invalid crypt:0  Rx invalid frag:0
          Tx excessive retries:2  Invalid misc:0   Missed beacon:0
    """
    try:
        lines = ok.stdout.split('\r\n')
        essid = lines[0].split("ESSID:")[1]
        signal = lines[5].split('Signal level=')[1].strip()
    except Exception as e:
        log.error("Error:{} parsing iwconfig".format(str(e)))
        return {}
    return dict(signal=signal, essid=essid)


if __name__ == "__main__":
    import argparse

    parser = argparse.ArgumentParser(description='Control sensors on the board')

    parser.add_argument('sensor',
                        choices=['lights',
                                 'red_led',
                                 'ir_led',
                                 'temperature',
                                 'speakers',
                                 'scan',
                                 'buttons',
                                 'scan',
                                 'cpu',
                                 'wifi'
                                 ],
                        help='sensor to affect')

    parser.add_argument('parameter',
                        nargs='*',
                        help="option parameter for lights")

    pargs = parser.parse_args()
    if pargs.sensor == 'temperature':
        if pargs.parameter:
            bus = int(pargs.parameter[0])
            address = int(pargs.parameter[1],16)
            temp_c = temperature(bus,address)
        else:
            temp_c = temperature()
        temp_f = (temp_c * 1.8) + 32
        print(f"Celcius:{temp_c} Fahrenheit:{temp_f}")

    elif pargs.sensor == 'red_led':
        log.info(f"red_led:{red_led(*pargs.parameter)}")

    elif pargs.sensor == 'ir_led':
        ir_led(*pargs.parameter)
    
    elif pargs.sensor == 'lights':
        lights(*pargs.parameter)
        log.info("Current state of lights {}".format(state.lights))

    elif pargs.sensor == 'speakers':
        #speakers('play',os.path.join(HOME,'lullaby.wav'))
        job = speakers('play')
        job = psutil.Process(job.pid)
        while True:
            if not job.status() in ('running','sleeping'):
                break
            time.sleep(1)
        print("Done playing")


    elif pargs.sensor == 'microphone':
        microphone('on')

    elif pargs.sensor == 'scan':
        print(i2c_scan())

    elif pargs.sensor == 'cpu':
        print(f"CPU Temperature:{cpu()}")

    else:
        buttons()

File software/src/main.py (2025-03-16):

import os
import time

import sensorctl

from threading  import Thread

from log        import log
from iot_server import thing_shadow

HOME = os.path.dirname(os.path.realpath(__file__))

class Button(Thread):
    """
    Watch and handle the button
    :return:
    """
    def run(self):
        log.info("Starting button")
        try:
            sensorctl.buttons()
            while True:
                time.sleep(1)
        except Exception as e:
            log.error("Error {} on button".format(str(e)))


class Shadow(Thread):
    """
    Start the AWS Shadow service
    """
    def run(self):
        log.info("Starting shadow service")
        try:
            thing_shadow()
            while True:
                time.sleep(1)

        except Exception as e:
            log.error("Error {} on button".format(str(e)))



def main():
    """
    Main loop which starts multiple threads
    :return:
    """
    sensorctl.ir_led('off')
    sensorctl.red_led('off')
    sensorctl.lights('blink', 3)
    log.info(f"Current temperature:{sensorctl.temperature()}")

    # Start each of the threads that monitor button, water, and schedule
    button = Button()
    button.start()

    shadow = Shadow()
    shadow.start()

    jobs = [button, shadow]
    while True:

        # Check each job in the case it stops for some reason, and if not restart it
        for jn, job in enumerate(jobs):
            try:
                job.join(0)
            except Exception as e:
                log.error(f"Error:{e} trying to join job #{jn}")

            # If a job is dead, create a new one and restart it
            if not job.is_alive():
                if jn == 0:
                    log.info("Restarting Button")
                    jobs[jn] = Button()
                if jn == 1:
                    log.info("Restarting Shadow")
                    jobs[jn] = Shadow()
                jobs[jn].start()
                break
        time.sleep(5)


if __name__ == '__main__':
    log.info("MAIN IOT STARTING")
    main()

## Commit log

2025-02-05 add wav file initialize main and run buttons forever
2025-02-20 change I2c address to 49
2025-03-14 Code and hardware
    [Hera.kicad_pcb, Hera.kicad_sch, Hera_audio.kicad_sch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]
